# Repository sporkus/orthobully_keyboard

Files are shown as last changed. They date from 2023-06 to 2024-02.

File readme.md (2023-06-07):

Ortholinear PCB for bully keyboard
------------------------------

This is a "split" Ortholinear pcb made for [Bully keyboard](https://mkh.works/#bully).

### Features
- 5 columns on each side, with a 3 column center cluster
- RP2040

### Supported layouts
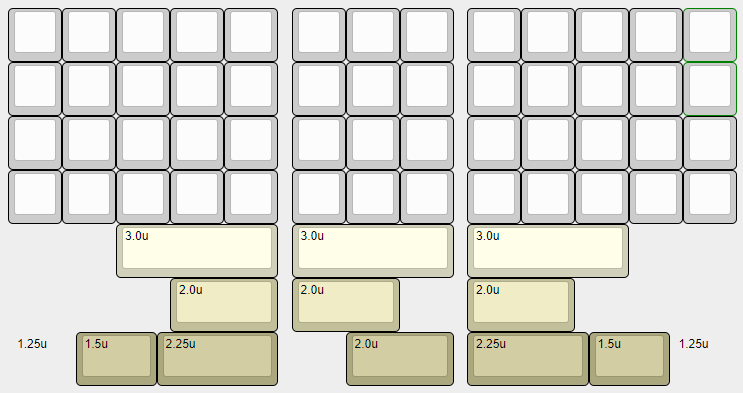
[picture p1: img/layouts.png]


### Production files
JLCPCB [production files](pcb/production) are provided. Components placement should be correct, but as always, do your own diligence when odering.

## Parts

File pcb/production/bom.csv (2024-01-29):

Designator | Footprint | Quantity | Value | LCSC Part #
C1, C10, C11, C12, C13, C14, C15, C5, C6, C9 | 402 | 10 | 100nF | C1525
C16, C17, C4, C7 | 402 | 4 | 1uF | C52923
C2, C3 | 402 | 2 | 22pF | C1555
C8 | 402 | 1 | 10uF | C15525
D1, D10, D11, D12, D13, D14, D15, D16, D17, D18, D19, D2, D20, D21, D22, D23, D24, D25, D26, D27, D28, D29, D3, D30, D31, D32, D33, D34, D35, D36, D37, D38, D39, D4, D40, D41, D42, D43, D44, D45, D46, D47, D48, D49, D5, D50, D51, D52, D6, D7, D8, D9 | D_SOD-123 | 52 | 1N4148W | C81598
J1 | JST-SR-4 | 1 | SM04B-SRSS-TB(LF)(SN) | C3029343
R1, R7 | 402 | 2 | 1k | C11702
R5, R6 | 402 | 2 | 27R | C25092
U1 | SOIC-8_5.23x5.23mm_P1.27mm | 1 | W25Q128JVS | C97521
U3 | RP2040-QFN-56 | 1 | RP2040 | C2040
U4 | SOT-23 | 1 | XC6206PxxxMR-Regulator_Linear | C5446
Y1 | Crystal_SMD_3225-4Pin_3.2x2.5mm | 1 | 12MHz | C9002
SW_BOOT1 | TL3342 | 1 | SKQG | C318884
SW_RST1 | TL3342 | 1 | SKQG | C318884

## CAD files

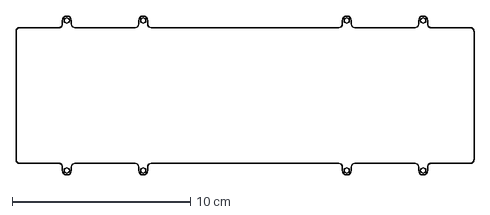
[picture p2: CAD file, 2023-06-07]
misc/edgecuts.dxf
25.7 x 8.92 cm

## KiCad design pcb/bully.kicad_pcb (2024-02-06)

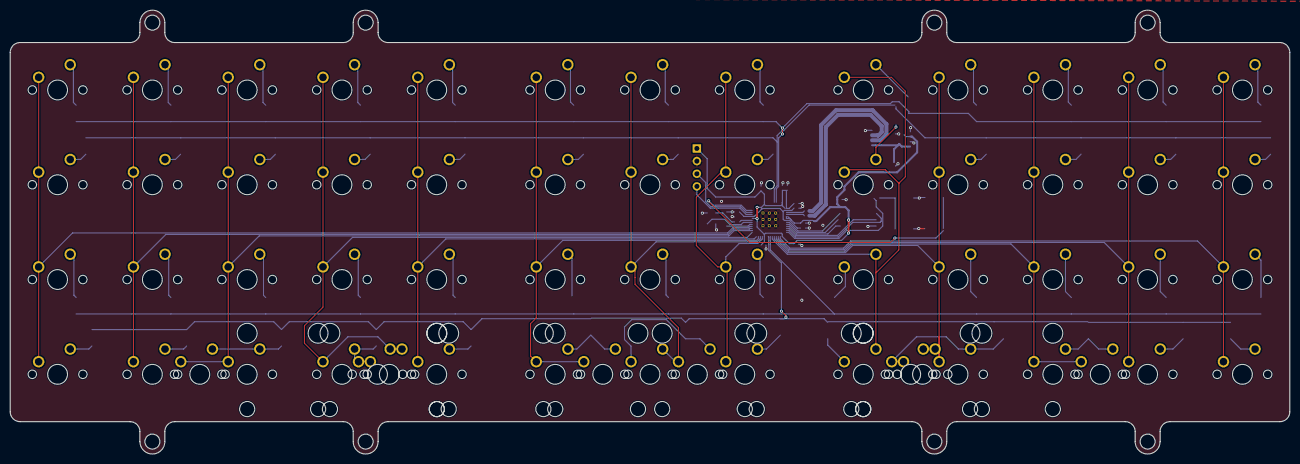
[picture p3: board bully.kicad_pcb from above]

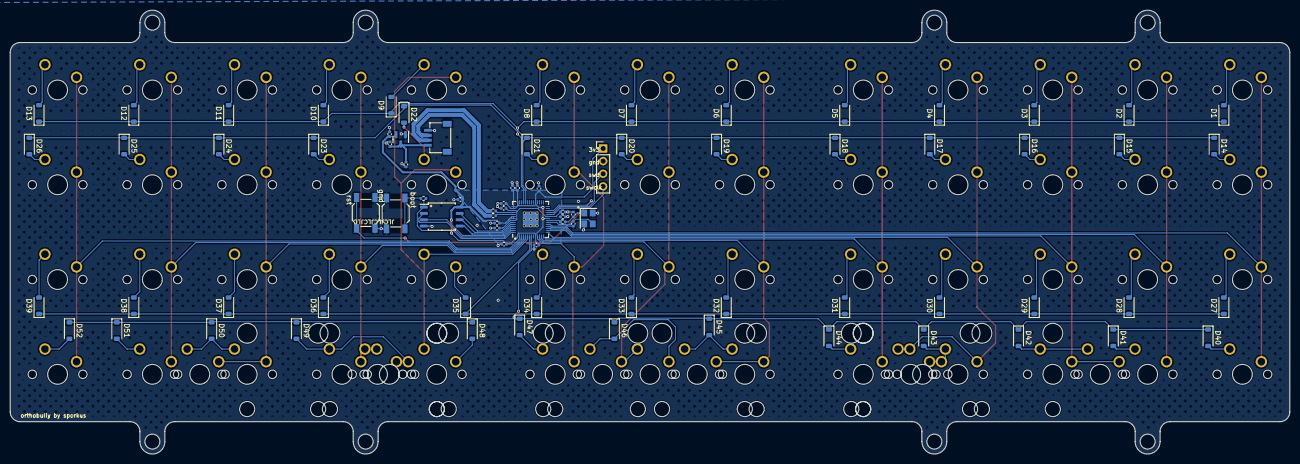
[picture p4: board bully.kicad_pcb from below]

Board: 2 copper layers, 257.2 x 89.2 mm, 141 parts (81 on the bottom side), 90 nets.

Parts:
C1, C5, C6, C9, C10, C11, C12, C13, C14, C15: 100nF; C_0402_1005Metric
C2, C3: 22pF; C_0402_1005Metric
C4, C7, C16, C17: 1uF; C_0402_1005Metric
C8: 10uF; C_0402_1005Metric
D1, D2, D3, D4, D5, D6, D7, D8, D9, D10, D11, D12, D13, D14, D15, D16, D17, D18, D19, D20, D21, D22, D23, D24, D25, D26, D27, D28, D29, D30, D31, D32, D33, D34, D35, D36, D37, D38, D39, D40, D41, D42, D43, D44, D45, D46, D47, D48, D49, D50, D51, D52: 1N4148W; D_SOD-123
J1: SM04B-SRSS-TB(LF)(SN); JST-SR-4
J2: Conn_01x04; PinHeader_1x04_P2.54mm_Vertical
R1, R7: 1k; R_0402_1005Metric
R5, R6: 27R; R_0402_1005Metric
SW1, SW2, SW3, SW4, SW5, SW6, SW7, SW8, SW9, SW10, SW11, SW12, SW13, SW14, SW15, SW16, SW17, SW18, SW19, SW20, SW21, SW22, SW23, SW24, SW25, SW26, SW27, SW28, SW29, SW30, SW31, SW32, SW33, SW34, SW35, SW36, SW37, SW38, SW39, SW40, SW41, SW42, SW44, SW45, SW47, SW48, SW50, SW51, SW52: SW_Push; MX-Solderable-1U
SW43, SW46, SW49: SW_Push; MX-Solderable-3U-ReversedStabilizers
SW53, SW54, SW55, SW56: SW_Push; MX-Solderable-2U-ReversedStabilizers
SW57, SW60: SW_Push; MX-Solderable-1.5U
SW58, SW59: SW_Push; MX-Solderable-2.25U-ReversedStabilizers
SW_BOOT1: SKQGABE010; SW_SPST_SKQG_WithoutStem
SW_RST1: SKQGABE010; SW_SPST_SKQG_WithoutStem
U1: W25Q128JVS; SOIC-8_5.23x5.23mm_P1.27mm
U3: RP2040; RP2040-QFN-56
U4: XC6206PxxxMR-Regulator_Linear; SOT-23
Y1: 12MHz; Crystal_SMD_3225-4Pin_3.2x2.5mm

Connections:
+1V1: C4.1, C5.1, C6.1, U3.23 (DVDD), U3.45 (VREG_VOUT), U3.50 (DVDD)
+3V3: C1.1, C7.1, C9.1, C10.1, C11.1, C12.1, C13.1, C14.1, C15.1, C17.2, J2.1, U1.8 (VCC), U3.1 (IOVDD), U3.10 (IOVDD), U3.22 (IOVDD), U3.33 (IOVDD), U3.42 (IOVDD), U3.43 (ADC_AVDD), U3.44 (VREG_VIN), U3.48 (USB_VDD), U3.49 (IOVDD), U4.2 (VO)
+5V: C8.1, C16.2, J1.1, U4.3 (VI)
/D_+: R5.2, U3.47 (D+)
/D_-: R6.2, U3.46 (D-)
/XTAL_O: C3.2, R7.1, Y1.1
/~USB_BOOT: R1.1, SW_BOOT1.2
COL1: SW1.1, SW14.1, SW27.1, SW40.1, U3.18 (GPIO15)
COL2: SW2.1, SW15.1, SW28.1, SW41.1, U3.17 (GPIO14)
COL3: SW3.1, SW16.1, SW29.1, SW42.1, SW57.1, U3.16 (GPIO13)
COL4: SW4.1, SW17.1, SW30.1, SW43.1, SW53.2, SW58.2, U3.15 (GPIO12)
COL5: SW5.1, SW18.1, SW31.1, SW44.1, U3.14 (GPIO11)
COL6: SW6.1, SW19.1, SW32.1, SW45.1, SW54.1, U3.13 (GPIO10)
COL7: SW7.1, SW20.1, SW33.1, SW46.2, SW55.1, U3.12 (GPIO9)
COL8: SW8.1, SW21.1, SW34.1, SW47.1, U3.11 (GPIO8)
COL9: SW9.1, SW22.1, SW35.2, SW48.2, U3.6 (GPIO4)
COL10: SW10.1, SW23.1, SW36.1, SW49.1, SW56.2, SW59.2, U3.5 (GPIO3)
COL11: SW11.1, SW24.1, SW37.1, SW50.1, SW60.1, U3.4 (GPIO2)
COL12: SW12.1, SW25.1, SW38.1, SW51.1, U3.3 (GPIO1)
COL13: SW13.1, SW26.1, SW39.1, SW52.1, U3.2 (GPIO0)
D_N: J1.2, R6.1
D_P: J1.3, R5.1
GND: C1.2, C2.1, C3.1, C4.2, C5.2, C6.2, C7.2, C8.2, C9.2, C10.2, C11.2, C12.2, C13.2, C14.2, C15.2, C16.1, C17.1, J1.4, J2.2, SW_BOOT1.1, SW_RST1.1, U1.4 (GND), U3.19 (TESTEN), U3.57 (GND), U4.1 (GND), Y1.2, Y1.4
unnamed: D1.2 (A), SW1.2
unnamed: D2.2 (A), SW2.2
unnamed: D3.2 (A), SW3.2
unnamed: D4.2 (A), SW4.2
unnamed: D5.2 (A), SW5.2
unnamed: D6.2 (A), SW6.2
unnamed: D7.2 (A), SW7.2
unnamed: D8.2 (A), SW8.2
unnamed: D9.2 (A), SW9.2
unnamed: D10.2 (A), SW10.2
unnamed: D11.2 (A), SW11.2
unnamed: D12.2 (A), SW12.2
unnamed: D13.2 (A), SW13.2
unnamed: D14.2 (A), SW14.2
unnamed: D15.2 (A), SW15.2
unnamed: D16.2 (A), SW16.2
unnamed: D17.2 (A), SW17.2
unnamed: D18.2 (A), SW18.2
unnamed: D19.2 (A), SW19.2
unnamed: D20.2 (A), SW20.2
unnamed: D21.2 (A), SW21.2
unnamed: D22.2 (A), SW22.2
unnamed: D23.2 (A), SW23.2
unnamed: D24.2 (A), SW24.2
unnamed: D25.2 (A), SW25.2
unnamed: D26.2 (A), SW26.2
unnamed: D27.2 (A), SW27.2
unnamed: D28.2 (A), SW28.2
unnamed: D29.2 (A), SW29.2
unnamed: D30.2 (A), SW30.2
unnamed: D31.2 (A), SW31.2
unnamed: D32.2 (A), SW32.2
unnamed: D33.2 (A), SW33.2
unnamed: D34.2 (A), SW34.2
unnamed: D35.2 (A), SW35.1
unnamed: D36.2 (A), SW36.2
unnamed: D37.2 (A), SW37.2
unnamed: D38.2 (A), SW38.2
unnamed: D39.2 (A), SW39.2
unnamed: D40.2 (A), SW40.2
unnamed: D41.2 (A), SW41.2
unnamed: D42.2 (A), SW42.2, SW57.2
unnamed: D43.2 (A), SW43.2, SW53.1, SW58.1
unnamed: D44.2 (A), SW44.2
unnamed: D45.2 (A), SW45.2, SW54.2
unnamed: D46.2 (A), SW46.1, SW55.2
unnamed: D47.2 (A), SW47.2
unnamed: D48.2 (A), SW48.1
unnamed: D49.2 (A), SW49.2, SW56.1, SW59.1
unnamed: D50.2 (A), SW50.2, SW60.2
unnamed: D51.2 (A), SW51.2
unnamed: D52.2 (A), SW52.2
QSPI_CLK: U1.6 (CLK), U3.52 (QSPI_SCLK)
QSPI_SS: R1.2, U1.1 (~CS), U3.56 (QSPI_SS_N)
ROW1: D1.1 (K), D2.1 (K), D3.1 (K), D4.1 (K), D5.1 (K), D6.1 (K), D7.1 (K), D8.1 (K), D9.1 (K), D10.1 (K), D11.1 (K), D12.1 (K), D13.1 (K), U3.39 (GPIO27/ADC1)
ROW2: D14.1 (K), D15.1 (K), D16.1 (K), D17.1 (K), D18.1 (K), D19.1 (K), D20.1 (K), D21.1 (K), D22.1 (K), D23.1 (K), D24.1 (K), D25.1 (K), D26.1 (K), U3.38 (GPIO26/ADC0)
ROW3: D27.1 (K), D28.1 (K), D29.1 (K), D30.1 (K), D31.1 (K), D32.1 (K), D33.1 (K), D34.1 (K), D35.1 (K), D36.1 (K), D37.1 (K), D38.1 (K), D39.1 (K), U3.7 (GPIO5)
ROW4: D40.1 (K), D41.1 (K), D42.1 (K), D43.1 (K), D44.1 (K), D45.1 (K), D46.1 (K), D47.1 (K), D48.1 (K), D49.1 (K), D50.1 (K), D51.1 (K), D52.1 (K), U3.8 (GPIO6)
SD0: U1.5 (DI(IO0)), U3.53 (QSPI_SD0)
SD1: U1.2 (DO(IO1)), U3.55 (QSPI_SD1)
SD2: U1.3 (IO2), U3.54 (QSPI_SD2)
SD3: U1.7 (IO3), U3.51 (QSPI_SD3)
SWCLK: J2.4, U3.24 (SWCLK)
SWD: J2.3, U3.25 (SWDIO)
XTAL_IN: C2.2, U3.20 (XTAL_IN), Y1.3
XTAL_OUT: R7.2, U3.21 (XTAL_OUT)
~RESET: SW_RST1.2, U3.26 (~RUN)

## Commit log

2023-06-07 looks good for ordering but entirely untested
    [bom.csv, bully.kicad_pcb, bully.kicad_sch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]
2023-06-16 updated bom
    [bom.csv, bully.kicad_sch, key_matrix.kicad_sch]
2024-01-29 Added JLC part numbers, remove unused parts from BOM and position files
    [bom.csv, positions.csv]
2024-02-06 Added 150/225 bottom row for hhkb support
    Fixed positions of many bottom row alternate layouts. No BOM changes, just moved one diode and a few conflicting traces.
    Gerbers have been updated
    [bully.kicad_pcb, key_matrix.kicad_sch, positions.csv]
